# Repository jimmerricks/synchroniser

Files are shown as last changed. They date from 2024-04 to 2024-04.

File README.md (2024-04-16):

# Synchroniser

This Eurorack module is a hand-solderable 4hp version of [Hagiwo's Clock Sync LFO](https://note.com/solder_state/n/n4c600f2431c3). It is based on [the schematics and design by mzuelch](https://github.com/mzuelch/CATs-Eurosynth/tree/main/Modules/HAGIWO/Sync%20LFO) but adds a couple of buttons and an extra LED. It is Arduino Nano based and compatible with firmware released by [mzuelch](https://github.com/mzuelch/CATs-Eurosynth/tree/main/Modules/HAGIWO/Sync%20LFO/Firmware), [awonak](https://awonak.github.io/HagiwoModulove/synclfo/) and [Modulove](https://dl.modulove.de/module/synclfo/).

## BOM

Use the [ibom](https://htmlpreview.github.io/?https://github.com/jimmerricks/synchroniser/blob/main/bom/ibom.html) to assist with sourcing components, and as a placement guide when building the module.

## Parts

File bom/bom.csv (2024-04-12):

Id | Designator | Footprint | Quantity | Designation | Reference
1 | C1,C3,C2,C4 | C_0805_2012Metric | 4 | 220p | GCM2165C1H221JA16D
2 | D2,D5 | LED_D3.0mm | 2 | LED | WP710A10ED
3 | J3 | Jack_3.5mm_QingPu_WQP-PJ301M-12 | 1 | BP_Inv_Out | eg. Thonk
4 | J4 | Jack_3.5mm_QingPu_WQP-PJ301M-12 | 1 | BP_Out
5 | P1,P3,P4 | Potentiometer_AlpsAlpine_RK09L1140_wo_Fix | 3 | B100K | eg. Thonk
6 | P2 | Potentiometer_AlpsAlpine_RK09L1140 | 1 | B100K
7 | R3,R1,R2,R4 | R_0805_2012Metric | 4 | 470R | RC0805FR-07470RL
8 | J2 | Jack_3.5mm_QingPu_WQP-PJ301M-12 | 1 | CLK In
9 | J1 | Jack_3.5mm_QingPu_WQP-PJ301M-12 | 1 | UP_Out
10 | SW1,SW2 | SW_PUSH_6mm | 2 | Button | TL1105SPF100Q (cap: 1RBLK)
11 | A1 | Arduino_Nano | 1 | Arduino_Nano_v3.x | eg. AliExpress (sockets: 90147-1115)
12 | C5 | C_0805_2012Metric | 1 | 6.8n | GRM2195C1H682JA01J
13 | C6 | C_0805_2012Metric | 1 | 10n | GCM216R71H103JA37D
14 | C7,C9,C10,C12,C13 | C_0805_2012Metric | 5 | 100n | GCM21BR71H104JA37L
15 | C8,C11 | CP_EIA-3216-18_Kemet-A | 2 | 10u | C1206C106J3RACAUTO
16 | D1 | SOT-23_Handsoldering | 1 | BAV99,215 | BAV99,215
17 | D3,D4 | D_SOD-123 | 2 | 1N5819 | 1N5819HW-7-F
18 | J5 | Power_2x5_Vertical | 1 | Power | 90131-1085
19 | R5 | R_0805_2012Metric | 1 | 13k | RC0805FR-0713KL
20 | R6 | R_0805_2012Metric | 1 | 27k | RC0805FR-0727KL
21 | R7,R10,R16,R21 | R_0805_2012Metric | 4 | 1k | RC0805FR-071KL
22 | R8,R22 | R_0805_2012Metric | 2 | 300R | RC0805FR-07300RL
23 | R9,R13,R15,R17,R18,R19,R20,R11 | R_0805_2012Metric | 8 | 10k | RC0805FR-0710KL
24 | R12 | R_0805_2012Metric | 1 | 100k | RC0805FR-07100KL
25 | R14 | R_0805_2012Metric | 1 | 20k | RC0805FR-0720KL
26 | U1,U2 | SOIC-8_3.9x4.9mm_P1.27mm | 2 | TL072 | TL072CDR

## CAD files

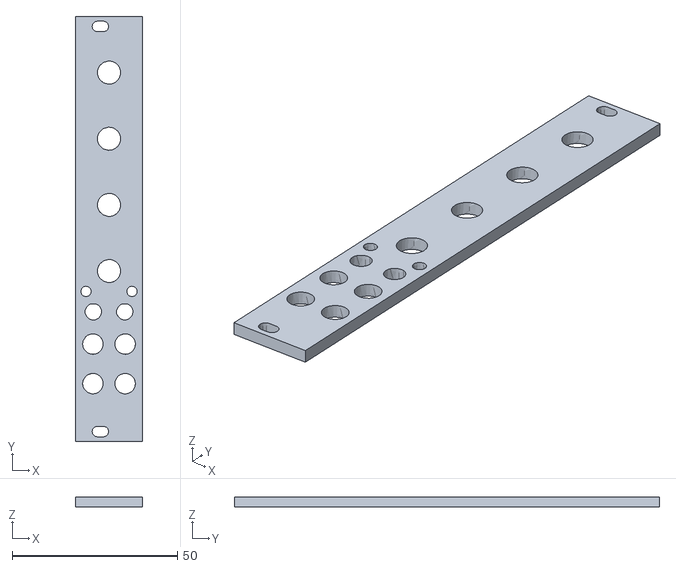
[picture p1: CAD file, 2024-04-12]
pnl/panel-3u.stl
20.2 x 128.5 x 3.00

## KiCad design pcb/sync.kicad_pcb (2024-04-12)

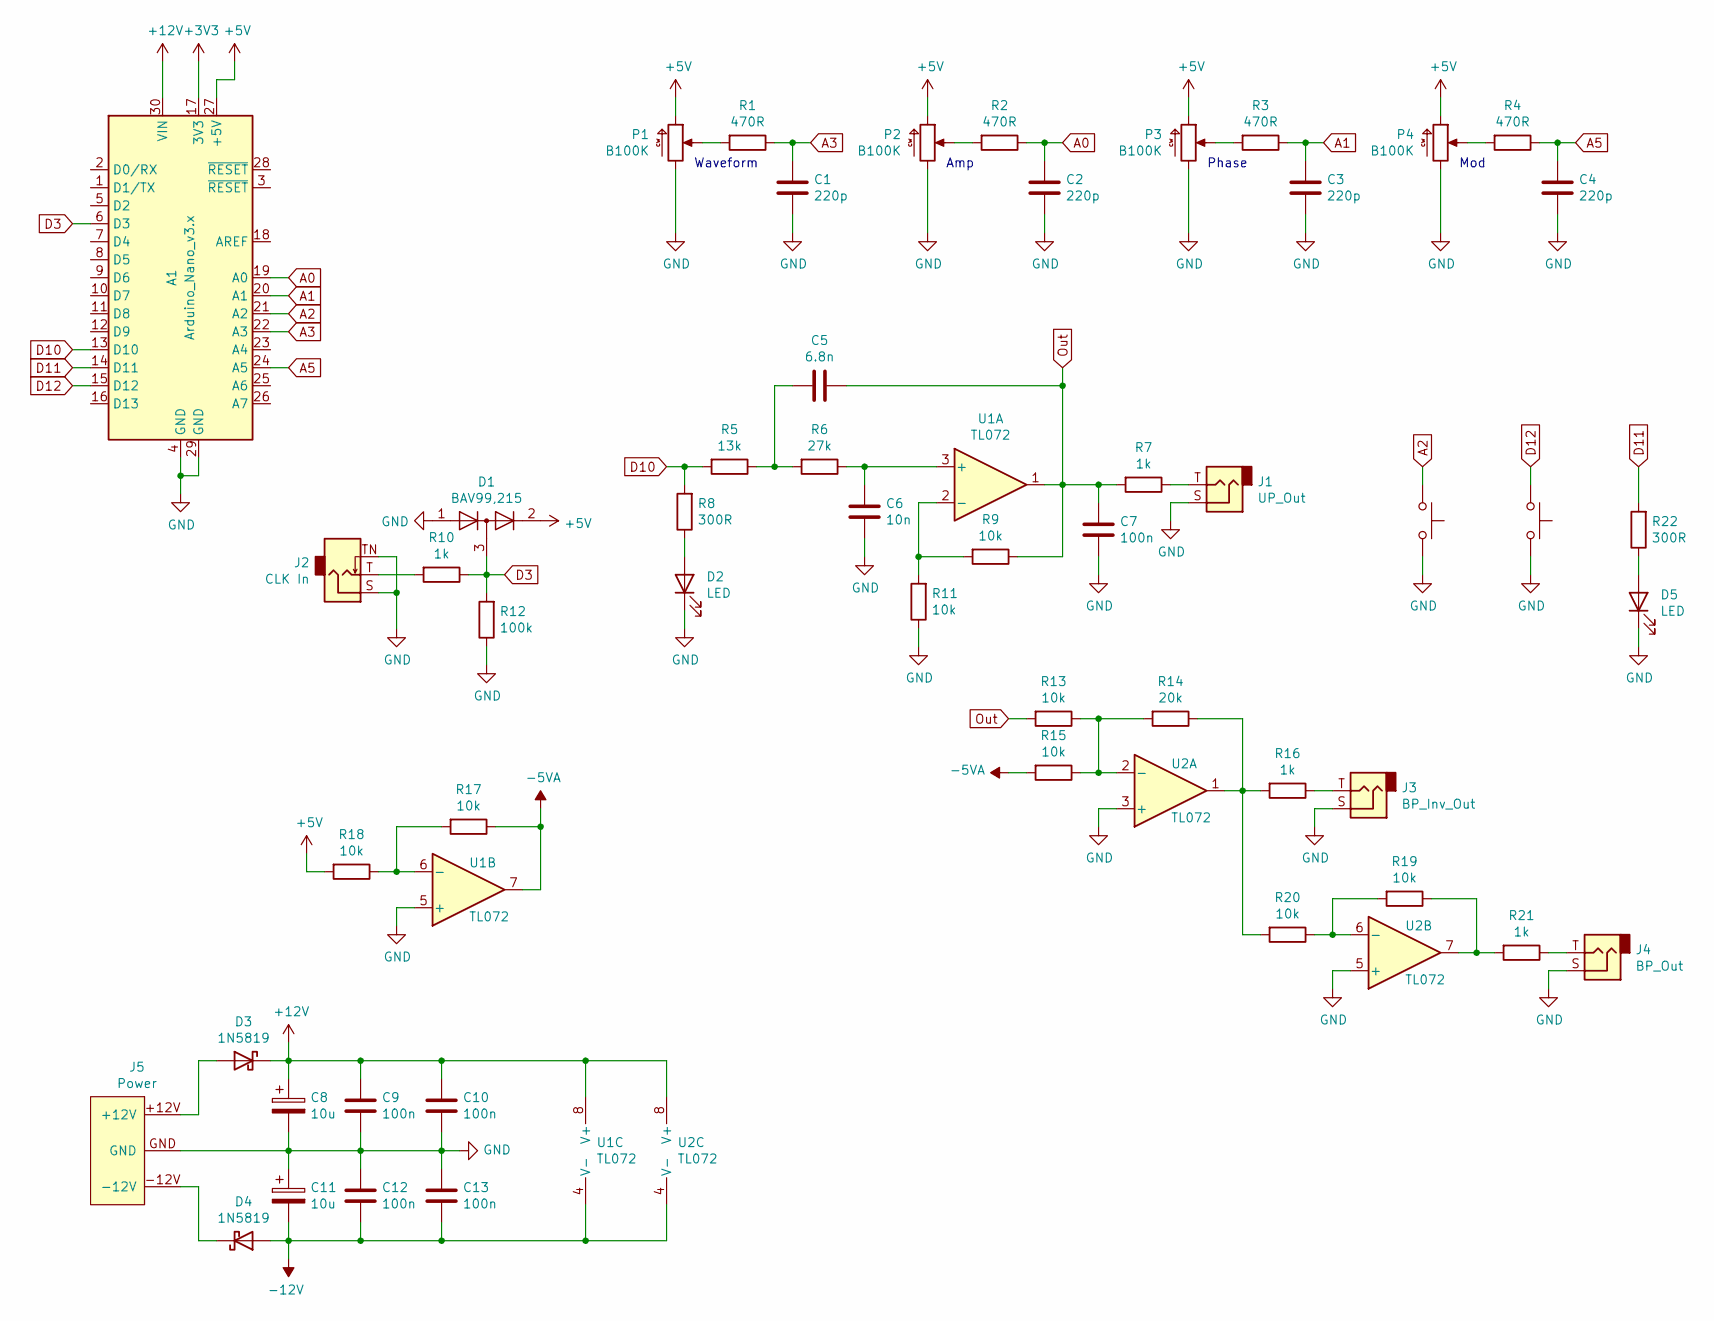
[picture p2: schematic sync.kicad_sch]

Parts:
A1: Arduino_Nano_v3.x; Arduino_Nano
C1, C2, C3, C4: 220p; C_0402_1005Metric; LCSC C1530
C5: 6.8n; C_0402_1005Metric; LCSC C1542
C6: 10n; C_0402_1005Metric; LCSC C15195
C7, C9, C10, C12, C13: 100n; C_0402_1005Metric; LCSC C1525
C8, C11: 10u; CP_EIA-3216-18_Kemet-A; LCSC C7171
D1: BAV99,215; SOT-23; LCSC C2500
D2, D5: LED; LED_D3.0mm
D3, D4: 1N5819; D_SOD-323; LCSC C191023
J1: UP_Out; Jack_3.5mm_QingPu_WQP-PJ301M-12
J2: CLK In; Jack_3.5mm_QingPu_WQP-PJ301M-12
J3: BP_Inv_Out; Jack_3.5mm_QingPu_WQP-PJ301M-12
J4: BP_Out; Jack_3.5mm_QingPu_WQP-PJ301M-12
J5: Power; Power_2x5_Vertical
P1, P3, P4: B100K; Potentiometer_AlpsAlpine_RK09L1140_wo_Fix
P2: B100K; Potentiometer_AlpsAlpine_RK09L1140
R1, R2, R3, R4: 470R; R_0402_1005Metric; LCSC C25117
R5: 13k; R_0603_1608Metric; LCSC C22797
R6: 27k; R_0402_1005Metric; LCSC C25771
R7, R10, R16, R21: 1k; R_0402_1005Metric; LCSC C11702
R8, R22: 300R; R_0402_1005Metric; LCSC C25102
R9, R11, R13, R15, R17, R18, R19, R20: 10k; R_0402_1005Metric; LCSC C25744
R12: 100k; R_0402_1005Metric; LCSC C25741
R14: 20k; R_0402_1005Metric; LCSC C25765
SW1, SW2: Button; SW_PUSH_6mm
U1, U2: TL072; SOIC-8_3.9x4.9mm_P1.27mm; LCSC C6961

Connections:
+3V3: A1.17 (3V3)
+5V: A1.27 (+5V), D1.2 (A), P1.CW, P2.CW, P3.CW, P4.CW, R18.2
+12V: A1.30 (VIN), C8.1, C9.2, C10.2, D3.1 (K), U1.8 (V+), U2.8 (V+)
-5VA: R15.2, R17.1, U1.7
-12V: C11.2, C12.1, C13.1, D4.2 (A), U1.4 (V-), U2.4 (V-)
A0: A1.19 (A0), C2.1, R2.1
A1: A1.20 (A1), C3.1, R3.1
A2: A1.21 (A2), SW1.1
A3: A1.22 (A3), C1.1, R1.1
A5: A1.24 (A5), C4.1, R4.1
D3: A1.6 (D3), D1.3 (K), R10.1, R12.2
D10: A1.13 (D10), R5.2, R8.2
D11: A1.14 (D11), R22.2
D12: A1.15 (D12), SW2.1
GND: A1.4 (GND), A1.29 (GND), C1.2, C2.2, C3.2, C4.2, C6.1, C7.1, C8.2, C9.1, C10.1, C11.1, C12.2, C13.2, D1.1 (K), D2.1 (K), D5.1 (K), J1.S, J2.S, J2.TN, J3.S, J4.S, J5.GND, P1.CCW, P2.CCW, P3.CCW, P4.CCW, R11.1, R12.1, SW1.2, SW2.2, U1.5 (+), U2.3 (+), U2.5 (+)
unnamed: C5.2, R5.1, R6.2
unnamed: D2.2 (A), R8.1
unnamed: D3.2 (A), J5.+12V
unnamed: D4.1 (K), J5.-12V
unnamed: D5.2 (A), R22.1
unnamed: J1.T, R7.1
unnamed: J2.T, R10.2
unnamed: J3.T, R16.1
unnamed: J4.T, R21.1
unnamed: P1.W, R1.2
unnamed: P2.W, R2.2
unnamed: P3.W, R3.2
unnamed: P4.W, R4.2
unnamed: R14.1, R16.2, R20.2, U2.1
unnamed: R19.1, R21.2, U2.7
unnamed: C6.2, R6.1, U1.3 (+)
unnamed: R9.2, R11.2, U1.2 (-)
unnamed: R17.2, R18.1, U1.6 (-)
unnamed: R13.1, R14.2, R15.1, U2.2 (-)
unnamed: R19.2, R20.1, U2.6 (-)
Out: C5.1, C7.2, R7.2, R9.1, R13.2, U1.1

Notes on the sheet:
Amp
Waveform
Phase
Mod

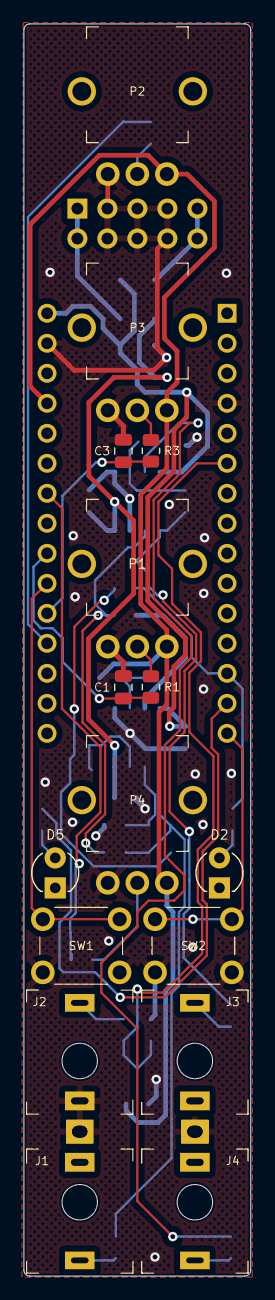
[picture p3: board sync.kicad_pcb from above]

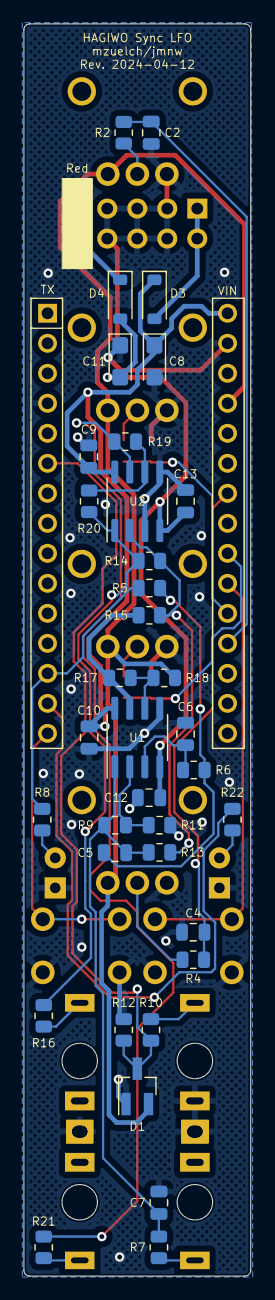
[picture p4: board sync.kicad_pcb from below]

Board: 2 copper layers, 19.2 x 106.0 mm, 54 parts (38 on the bottom side), 35 nets.

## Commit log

2024-04-12 Revised PCB files with the button connected to A2.
    [sync.kicad_pcb, sync.kicad_sch]
2024-04-12 Basic 3u panel for printing or cutting.
    [panel-3u.stl]
2024-04-12 BOM in both CSV and HTML versions.
    [bom.csv]
2024-04-16 Add bom link
